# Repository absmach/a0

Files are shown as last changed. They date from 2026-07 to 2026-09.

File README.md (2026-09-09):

# 🔌 A0 Gateway

a0 is a modular **IoT gateway** built around the **ESP32-C6 (RISC-V)** platform, offering advanced wireless capabilities such as **Wi-Fi 6**, **Bluetooth 5**, and **802.15.4**. It supports multiple connectivity options including NB-IoT/LTE-M, WMBUS, and sub-GHz, enabling secure and scalable IoT deployments across smart buildings, industrial environments, and city infrastructure.

Optimized for low-power, battery-powered operation and modular expansion, A0 integrates secure communication, local storage, and multiple radio interfaces to serve as a versatile edge gateway in modern IoT ecosystems. While it includes support for Wireless and Wired M-Bus, its primary focus is on broad IoT connectivity and interoperability.

<p align="center">
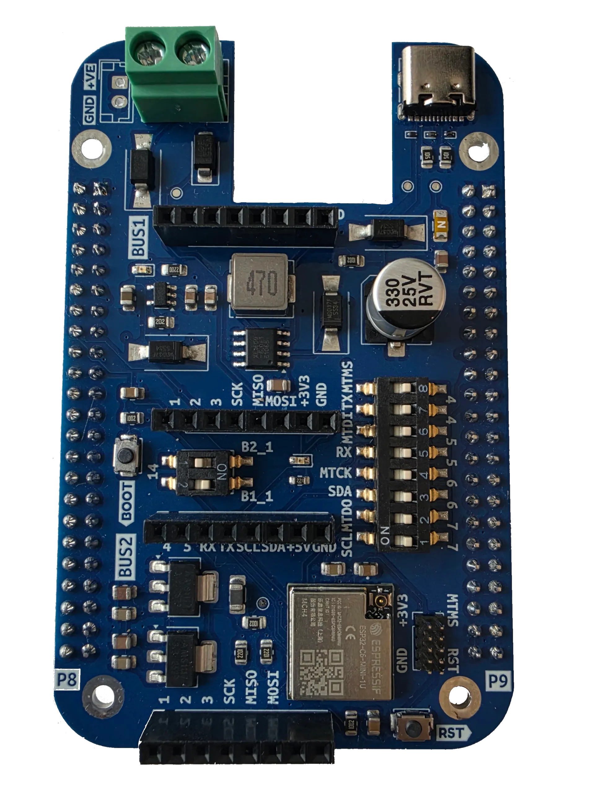
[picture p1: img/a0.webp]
A0 Board
  
</p>

## 🌟 Features

- ⚙️ **RISC-V Architecture**: Powered by ESP32-C6 with a RISC-V core for efficiency and flexibility.
- 📡 **Advanced Wireless Connectivity**: Supports Wi-Fi 6, Bluetooth 5, and 802.15.4 for robust IoT networking.
- 🌐 **Multiple Uplink Options**: Provides NB-IoT/LTE-M for reliable data transmission.
- 🔋 **Battery-Powered Operation**: Optimized for low-power deployments with long-lasting battery support.
- 🔐 **Advanced Security**: Includes RSA-3072 secure boot, AES-128/256-XTS flash encryption, digital signature, HMAC identity protection, and hardware cryptographic accelerators for performance. Built-in Trusted Execution Environment (TEE) ensures secure software separation.
- 🛠️ **Modular Design**: Optional carrier boards adds NB-IoT/LTE-M, WMBUS, and sub-GHz radio support.
- 🔗 **Flexible IoT Connectivity**: Integrates with [Magistrala](https://github.com/absmach/magistrala) using multiple IoT protocols, including MQTT, CoAP, HTTP, and WebSockets.
- 🧩 **Zephyr RTOS Support**: Compatible with Zephyr for real-time, reliable IoT applications.
- 🖥️ **WebAssembly Runtime**: Runs lightweight, portable edge logic with WAMR (WebAssembly Micro Runtime).
- 🌀 **Propeller Orchestrator Integration**: Works with [Propeller](https://github.com/absmach/propeller) for secure, policy-driven orchestration of IoT workloads across the edge-cloud continuum.
- 📈 **Future-Ready for IoT Ecosystems**: Designed for interoperability in smart buildings, industrial IoT, and city-scale deployments.

## 🛠️ How It Works

1. **Connect & Collect**  
   Gather data from IoT sensors and devices via Wireless/Wired M-Bus, Wi-Fi, BLE, or sub-GHz radio.

2. **Process at the Edge**  
   Use the **ESP32-C6** for real-time processing or deploy **WebAssembly (Wasm)** modules with **WAMR** for flexible edge logic execution.

3. **Ensure Security**  
   Protect data and code integrity with **secure boot**, **flash encryption**, and **TEE-based isolation**, leveraging ESP32-C6 hardware security features.

4. **Transmit to IoT Platform**  
   Send processed data using **NB-IoT/LTE-M**, supporting multiple protocols (**MQTT**, **CoAP**, **HTTP**, **WebSockets**) for seamless integration with [**Magistrala**](https://github.com/absmach/magistrala).

5. **Orchestrate & Scale**  
   Integrate with the [**Propeller Orchestrator**](https://github.com/absmach/propeller) for policy-driven deployment and orchestration of workloads across the edge-cloud continuum.

6. **Manage Remotely**  
   Perform **OTA updates**, monitor device health, and manage configurations through connected IoT management tools.

## 📖 Documentation

For setup instructions, pinouts, and integration guides, see the full documentation:  
🔗 [A0 Documentation](https://www.absmach.eu/docs/hardware/s1-gateway/)

## 💡 Use Cases

- 🏢 **Smart Buildings**: Connect heat and water meters via Wireless M-Bus for real-time monitoring.
- 🏭 **Industrial IoT**: Collect and transmit sensor data in secure and bandwidth-constrained environments.
- 🌍 **Smart Cities**: Enable large-scale metering infrastructure with NB-IoT and sub-GHz connectivity.
- 🔐 **Secure Data Acquisition**: Ensure encrypted communication from edge devices to the cloud.

## 🔧 Hardware Highlights

The system consists of a **base board (A0)** with plug-in **expansion modules**:

- **A0 Base Board** ([a0/](a0/README.md)):
  - MCU: **ESP32-C6** module (RISC-V architecture)
  - Connectivity: **Wi-Fi 6**, **Bluetooth 5**, **IEEE 802.15.4**
  - Security: **Secure Boot**, **Flash Encryption**, **TEE**, Hardware Crypto Accelerators
  - Power: **USB-C**, external power supply, or **battery** (with charging support)
  - Expansion: **2 module slots — BUS1 and BUS2** — for plug-in connectivity modules

- **Expansion Modules** (plug into BUS1/BUS2):
  - [**SIM7080G**](modules/sim7080g/README.md): NB-IoT / LTE-M cellular uplink + GNSS
  - [**WMBUS**](modules/wmbus/README.md): Wireless M-Bus metering radio
  - [**E07-400M10S**](modules/E07400M10S/README.md): Sub-GHz radio module (400 MHz, 10 dBm)

## 🤝 Contributing

Contributions are welcome! Please check the [CONTRIBUTING.md](#) for details on how to get started.

## 📜 License

A0 is licensed under the **Apache-2.0 License**. See the [LICENSE](LICENSE) file for more details.

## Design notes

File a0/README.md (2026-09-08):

# A0 Base Board

**A0** is the base board of the modular A0 IoT gateway, built around an **ESP32-C6 module** (RISC-V, Wi-Fi 6, Bluetooth 5, IEEE 802.15.4).

## About the ESP32-C6

The ESP32-C6 is Espressif's first Wi-Fi 6 SoC, integrating **2.4 GHz Wi-Fi 6 (802.11ax)**, **Bluetooth 5 (LE)** and **IEEE 802.15.4** (Thread/Zigbee) radio connectivity in a single low-power chip ([product page](https://www.espressif.com/en/products/socs/esp32-c6)).

| Spec | Details |
| --- | --- |
| **CPU** | High-performance 32-bit RISC-V core, up to **160 MHz**, plus a low-power (LP) 32-bit RISC-V core, up to **20 MHz** |
| **Memory** | 320 KB ROM, 512 KB SRAM, external flash |
| **Wireless** | 2.4 GHz Wi-Fi 6 (802.11ax, 20 MHz) with 802.11 b/g/n (20/40 MHz) backward compatibility; OFDMA up/downlink, downlink MU-MIMO, Target Wake Time (TWT); Bluetooth 5 LE with coded PHY long-range and 2 Mbps high-throughput PHY; IEEE 802.15.4 for Thread/Zigbee |
| **GPIO** | 30 (QFN40) or 22 (QFN32) programmable GPIOs |
| **Peripherals** | SPI, UART, I2C, I2S, RMT, TWAI, PWM, SDIO, Motor Control PWM, 12-bit ADC, temperature sensor |
| **Security** | RSA-3072 secure boot, AES-128/256-XTS flash encryption, digital signature and HMAC peripherals, hardware cryptographic accelerators, Trusted Execution Environment (TEE) for privilege/software separation |
| **Software** | Open-source ESP-IDF; ESP-Hosted / ESP-AT for co-processor use; ESP RainMaker; Zephyr support |

Wi-Fi 6 features (OFDMA, MU-MIMO, TWT) deliver low latency and long battery life even in congested RF environments, while combined Wi-Fi + BLE + 802.15.4 support makes it a natural fit for Matter end-point devices, Thread Border Routers, and Zigbee bridges.

## Overview

A0 provides everything needed to power and run the gateway, while pushing all radio/cellular connectivity onto removable expansion modules:

- **ESP32-C6 module on top** — main compute + Wi-Fi/BLE/802.15.4 connectivity, with hardware secure boot, flash encryption, and a TEE.
- **Power**:
  - USB-C power input
  - External power supply input
  - Battery support (with charging)
- **Expansion**: two module slots, **BUS1** and **BUS2**, where any of the following modules can be plugged in:
  - [SIM7080G](../modules/sim7080g/README.md) — NB-IoT/LTE-M cellular + GNSS
  - [WMBUS](../modules/wmbus/README.md) — Wireless M-Bus radio
  - [E07-400M10S](../modules/E07400M10S/README.md) — Sub-GHz radio (400 MHz, 10 dBm)

## Manufacturing

Gerber and assembly outputs are in [`jlcpcb/`](jlcpcb/) (`gerber/` and `production_files/`).

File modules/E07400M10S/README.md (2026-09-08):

# E07-400M10S Module

A plug-in expansion module for the [A0 base board](../../a0/README.md) based on the **Ebyte E07-400M10S** sub-GHz radio module.

## Overview

The E07-400M10S is a compact sub-GHz (400 MHz) RF transceiver module with 10 dBm output. Plug it into one of the A0 base board's expansion slots (**BUS1** or **BUS2**) to add low-power, long-range sub-GHz connectivity for private sensor networks and IEEE 802.15.4-style links.

## Key Features

- **Sub-GHz radio**: 400 MHz band, 10 dBm output power
- **Low power**: suited to battery-powered operation
- **Interface**: SPI / UART over the expansion bus
- **Power**: supplied from the expansion bus

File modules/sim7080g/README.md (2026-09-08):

# SIM7080G Module

A plug-in expansion module for the [A0 base board](../../a0/README.md) based on the **SIMCom SIM7080G**.

## Overview

The SIM7080G provides **NB-IoT / LTE-M (Cat-M)** cellular connectivity plus **GNSS** positioning. Plug it into one of the A0 base board's expansion slots (**BUS1** or **BUS2**) to add a reliable cellular uplink for NB-IoT and LTE-M deployments.

## Key Features

- **Cellular**: NB-IoT and LTE-M (Cat-M) uplink
- **GNSS**: GPS/GLONASS/BeiDou/Galileo positioning
- **Interface**: connects to the ESP32-C6 over UART via the expansion bus
- **Power**: supplied from the expansion bus

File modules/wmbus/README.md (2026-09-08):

# WMBUS Module

A plug-in expansion module for the [A0 base board](../../a0/README.md) implementing **Wireless M-Bus (EN 13757-4)**.

## Overview

The WMBUS module adds a Wireless M-Bus radio for reading utility meters (heat, water, gas, electricity). Plug it into one of the A0 base board's expansion slots (**BUS1** or **BUS2**) to enable smart metering deployments.

## Key Features

- **Wireless M-Bus (EN 13757-4)** communication
- Connects to the ESP32-C6 over the expansion bus
- Powered from the expansion bus

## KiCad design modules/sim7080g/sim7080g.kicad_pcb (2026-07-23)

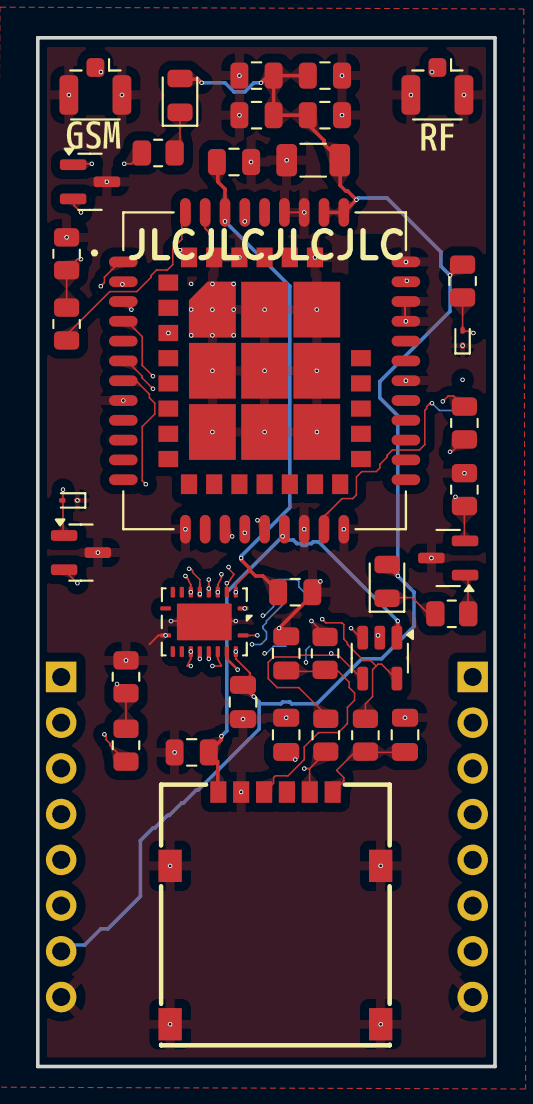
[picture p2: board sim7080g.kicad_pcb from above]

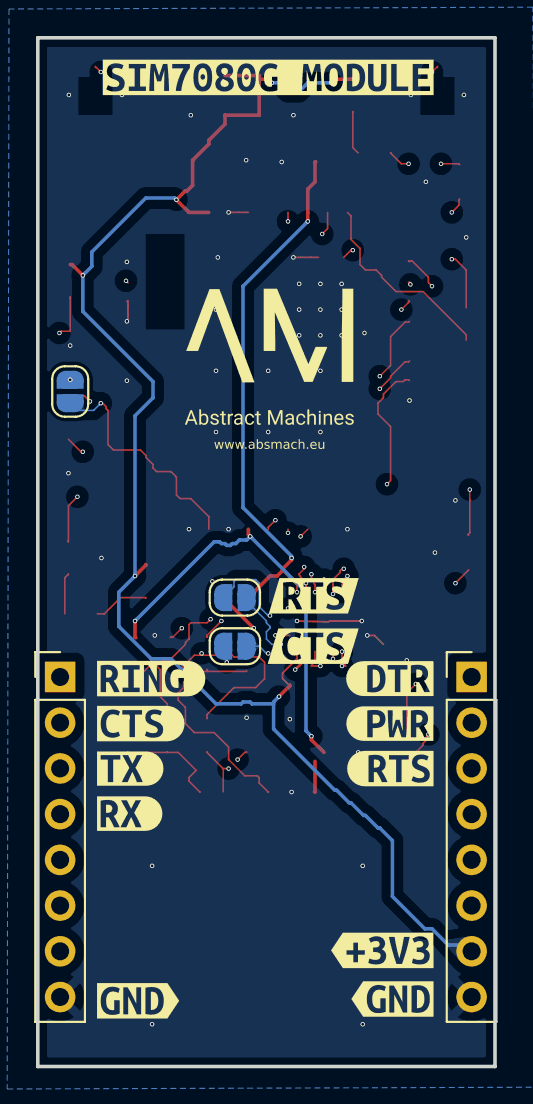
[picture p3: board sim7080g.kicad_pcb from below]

Board: 4 copper layers, 25.4 x 57.2 mm, 57 parts (18 on the bottom side), 39 nets.

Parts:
C1, C2, C5, C10, C11, C12, C13: 0.1uF; C_0805_2012Metric
C3: 10uF; C_0805_2012Metric
C6, C7, C8: 22pF; C_0805_2012Metric
C9: 100uF; C_1206_3216Metric
D1, D5: ESD9B5.0ST5G; D_SOD-923
D2: ESDA6V1SC5; SOT-23-5
D3, D4: LED; LED_0805_2012Metric
J1, J4: Conn_Coaxial; U.FL_Hirose_U.FL-R-SMT-1_Vertical
J2, J3: Conn_01x08; PinHeader_1x08_P2.54mm_Vertical
JP1, JP2, JP3: SolderJumper_2_Open; SolderJumper-2_P1.3mm_Open_RoundedPad1.0x1.5mm
Q1, Q2, Q3: NPN; SOT-23
R1: 10K; R_0805_2012Metric
R2, R8, R9: 4.7K; R_0805_2012Metric
R3, R4, R5: 22; R_0805_2012Metric
R6, R10, R11: 47K; R_0805_2012Metric
R7, R12: 100; R_0805_2012Metric
U1: TXB0108RGY; Texas_RGY_R-PVQFN-N20_EP2.05x3.05mm
U2: SIM7080G
U3: NANO SIM XG6P H1.35; SIM-SMD_NANO-SIM
kibuzzard-6A58AA2C: G***; kibuzzard-6A58AA2C
kibuzzard-6A58AA08: G***; kibuzzard-6A58AA08
kibuzzard-6A58AA80: G***; kibuzzard-6A58AA80
kibuzzard-6A58AA90: G***; kibuzzard-6A58AA90
kibuzzard-6A58AAA8: G***; kibuzzard-6A58AAA8
kibuzzard-6A58AAC0: G***; kibuzzard-6A58AAC0
kibuzzard-6A58AAD1: G***; kibuzzard-6A58AAD1
kibuzzard-6A58ABB3: G***; kibuzzard-6A58ABB3
kibuzzard-6A58ABC2: G***; kibuzzard-6A58ABC2
kibuzzard-6A58ABCC: G***; kibuzzard-6A58ABCC
kibuzzard-6A58ABD9: G***; kibuzzard-6A58ABD9
kibuzzard-6A58ABE5: G***; kibuzzard-6A58ABE5
kibuzzard-6A58AD62: G***; kibuzzard-6A58AD62
kibuzzard-6A58AD87: G***; kibuzzard-6A58AD87
kibuzzard-6A58ADF5: G***; kibuzzard-6A58ADF5

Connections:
+1V8: C1.2, C3.2, U1.2 (V_{CCA}), U2.40 (VDD_EXT)
+3V3: C2.2, C9.1, C10.1, C11.1, C12.1, C13.1, D3.2 (A), D4.2 (A), J2.7, R1.1, U1.19 (V_{CCB}), U2.34 (VBAT), U2.35 (VBAT__1)
GND: C1.1, C2.1, C3.1, C5.1, C6.1, C7.1, C8.1, C9.2, C10.2, C11.2, C12.2, C13.2, D1.1 (A1), D2.2 (A), D5.1 (A1), J1.2 (Ext), J2.8, J3.8, J4.2 (Ext), Q1.3 (E), Q2.3 (E), Q3.3 (E), R6.2, R10.2, R11.2, U1.11 (GND), U1.21 (GND), U2.8 (GND), U2.13 (GND__1), U2.19 (GND__2), U2.21 (GND__3), U2.27 (GND__4), U2.30 (GND__5), U2.31 (GND__6), U2.33 (GND__7), U2.36 (GND__8), U2.37 (GND__9), U2.45 (GND__10), U2.63 (GND__11), U2.66 (GND__12), U2.67 (GND__13), U2.69 (GND__14), U2.70 (GND__15), U2.71 (GND__16), U2.72 (GND__17), U2.73 (GND__18), U2.74 (GND__19), U2.75 (GND__20), U2.76 (GND__21), U2.77 (GND__22), U3.5 (GND), U3.8 (GND), U3.9 (GND), U3.10 (GND), U3.11 (GND)
GNSS_ANT: J1.1 (In), U2.68 (GNSS_ANT)
NETLIGHT: R9.1, U2.41 (NETLIGHT)
unnamed: D1.2 (A2), JP1.1 (A), R1.2
unnamed: D3.1 (K), R7.2
unnamed: D4.1 (K), R12.2
unnamed: JP1.2 (B), U2.20 (USB_BOOT)
unnamed: JP2.1 (A), U1.17 (B3)
unnamed: JP3.1 (A), U1.16 (B4)
unnamed: Q1.2 (B), R2.2, R6.1
unnamed: Q1.1 (C), R7.1
unnamed: Q2.2 (B), R8.2, R11.1
unnamed: Q3.2 (B), R9.2, R10.1
unnamed: Q3.1 (C), R12.1
unnamed: C7.2, R4.2, U3.3 (CLK)
unnamed: C8.2, R5.2, U3.7 (I/O)
unnamed: C6.2, R3.2, U3.2 (RST)
PWRKEY: D5.2 (A2), Q2.1 (C), U2.39 (PWRKEY)
RF_ANT: J4.1 (In), U2.32 (RF_ANT)
SIM7080G_CTS: J3.2, JP3.2 (B)
SIM7080G_DTR: J2.1, U1.15 (B5)
SIM7080G_PWR: J2.2, R8.1
SIM7080G_RING: J3.1, U1.14 (B6)
SIM7080G_RTS: J2.3, JP2.2 (B)
SIM7080G_RX: J3.4, U1.18 (B2)
SIM7080G_TX: J3.3, U1.20 (B1)
SIM_CLK: D2.4 (K), R4.1, U2.16 (SIM_CLK)
SIM_CTS: U1.5 (A4), U2.4 (UART1_CTS)
SIM_DATA: D2.5 (K), R5.1, U2.15 (SIM_DATA)
SIM_DTR: U1.6 (A5), U2.6 (UART1_DTR)
SIM_RI: U1.7 (A6), U2.7 (UART1_RI)
SIM_RST: D2.3 (K), R3.1, U2.17 (SIM_RST)
SIM_RTS: U1.4 (A3), U2.3 (UART1_RTS)
SIM_RX: U1.3 (A2), U2.2 (UART1_RXD)
SIM_TX: U1.1 (A1), U2.1 (UART1_TXD)
SIM_VDD: C5.2, D2.1 (K), U2.18 (SIM_VDD), U3.1 (VCC)
STATUS: R2.1, U2.42 (STATUS)

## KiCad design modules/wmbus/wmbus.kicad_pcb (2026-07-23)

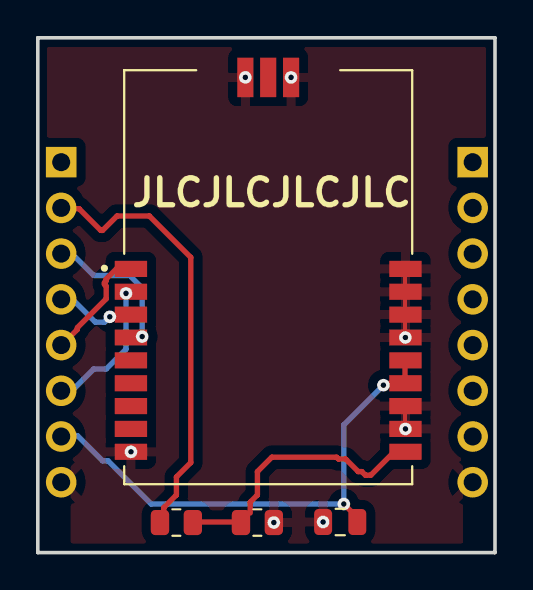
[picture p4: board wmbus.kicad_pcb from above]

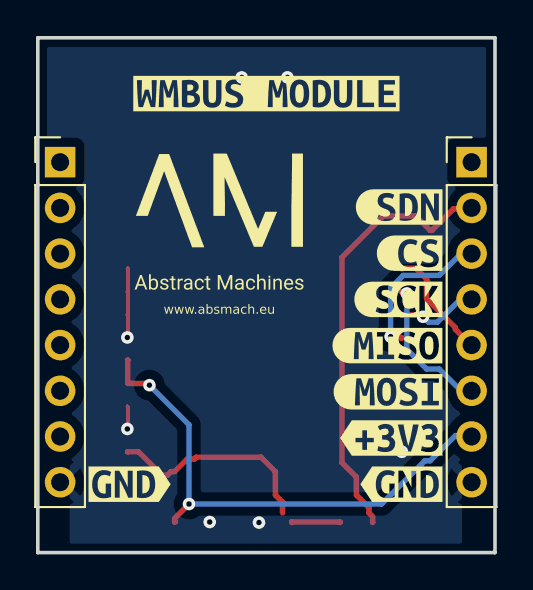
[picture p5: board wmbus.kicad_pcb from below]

Board: 2 copper layers, 25.4 x 28.6 mm, 15 parts (11 on the bottom side), 8 nets.

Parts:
C1: 0.1uF; C_0805_2012Metric
J1, J2: Conn_01x08; PinHeader_1x08_P2.54mm_Vertical
R1: 100; R_0805_2012Metric
R2: 10K; R_0805_2012Metric
U2: RC-S2LP-868
kibuzzard-6A563B7D: G***; kibuzzard-6A563B7D
kibuzzard-6A563B31: G***; kibuzzard-6A563B31
kibuzzard-6A563B41: G***; kibuzzard-6A563B41
kibuzzard-6A563B50: G***; kibuzzard-6A563B50
kibuzzard-6A563B65: G***; kibuzzard-6A563B65
kibuzzard-6A563B71: G***; kibuzzard-6A563B71
kibuzzard-6A563B88: G***; kibuzzard-6A563B88
kibuzzard-6A563B96: G***; kibuzzard-6A563B96
kibuzzard-6A563BEF: G***; kibuzzard-6A563BEF

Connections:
+3V3: C1.1, J1.7, U2.13 (VCC), U2.14 (VCC)
CS: J1.3, U2.4 (CSN)
GND: C1.2, J1.8, J2.8, R2.2, U2.9 (GND), U2.11 (GND), U2.12 (GND), U2.15 (GND), U2.16 (GND), U2.17 (GND), U2.18 (GND), U2.19 (GND), U2.21 (GND)
MISO: J1.5, U2.1 (SDO)
MOSI: J1.6, U2.2 (SDI)
unnamed: R1.2, R2.1, U2.10 (SDN)
SCK: J1.4, U2.3 (SCLK)
SDN: J1.2, R1.1

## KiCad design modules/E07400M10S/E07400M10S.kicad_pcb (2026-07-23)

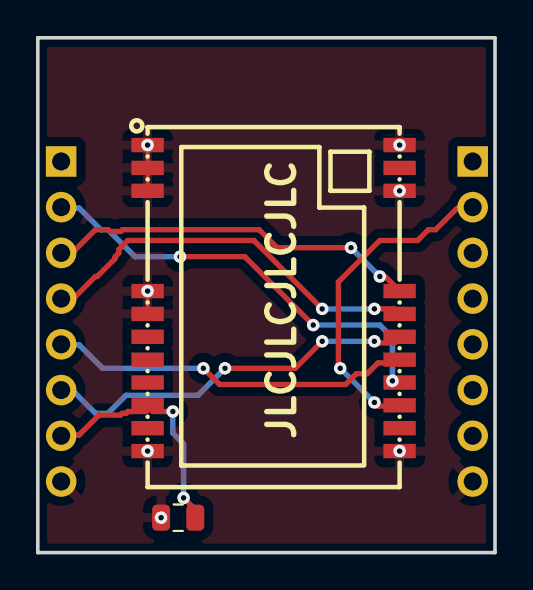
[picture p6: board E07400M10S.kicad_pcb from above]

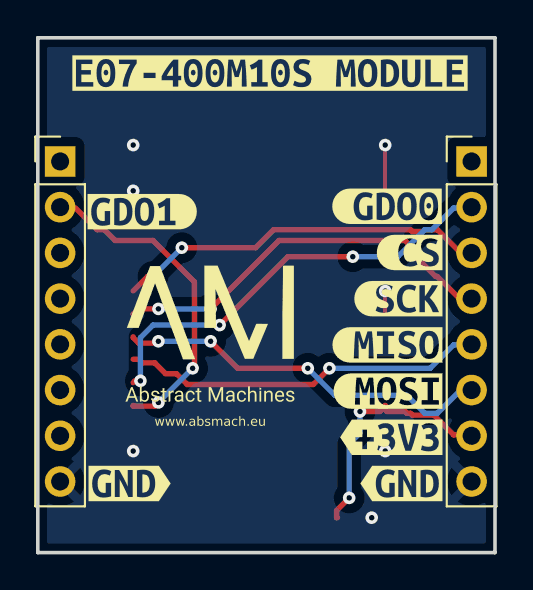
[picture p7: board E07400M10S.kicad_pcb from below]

Board: 2 copper layers, 25.4 x 28.6 mm, 14 parts (12 on the bottom side), 8 nets.

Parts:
C1: 0.1uF; C_0805_2012Metric
J1, J2: Conn_01x08; PinHeader_1x08_P2.54mm_Vertical
U1: E07-400M10S; C2965513
kibuzzard-6A5A4D23: G***; kibuzzard-6A5A4D23
kibuzzard-6A5A4D79: G***; kibuzzard-6A5A4D79
kibuzzard-6A5A4D90: G***; kibuzzard-6A5A4D90
kibuzzard-6A563B7D: G***; kibuzzard-6A563B7D
kibuzzard-6A563B41: G***; kibuzzard-6A563B41
kibuzzard-6A563B50: G***; kibuzzard-6A563B50
kibuzzard-6A563B65: G***; kibuzzard-6A563B65
kibuzzard-6A563B71: G***; kibuzzard-6A563B71
kibuzzard-6A563B88: G***; kibuzzard-6A563B88
kibuzzard-6A563B96: G***; kibuzzard-6A563B96

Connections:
+3V3: C1.1, J1.7, U1.9 (VCC)
CS: J1.3, U1.19 (CSN)
GDO0: J1.2, U1.15 (GD00)
GDO1: J2.2, U1.14 (GD02)
GND: C1.2, J1.8, J2.8, U1.1 (GND), U1.2 (GND), U1.3 (GND), U1.4 (GND), U1.5 (GND), U1.11 (GND), U1.12 (GND), U1.20 (GND), U1.22 (GND)
MISO: J1.5, U1.16 (MISO/GD01)
MOSI: J1.6, U1.17 (MOSI)
SCK: J1.4, U1.18 (SCK)

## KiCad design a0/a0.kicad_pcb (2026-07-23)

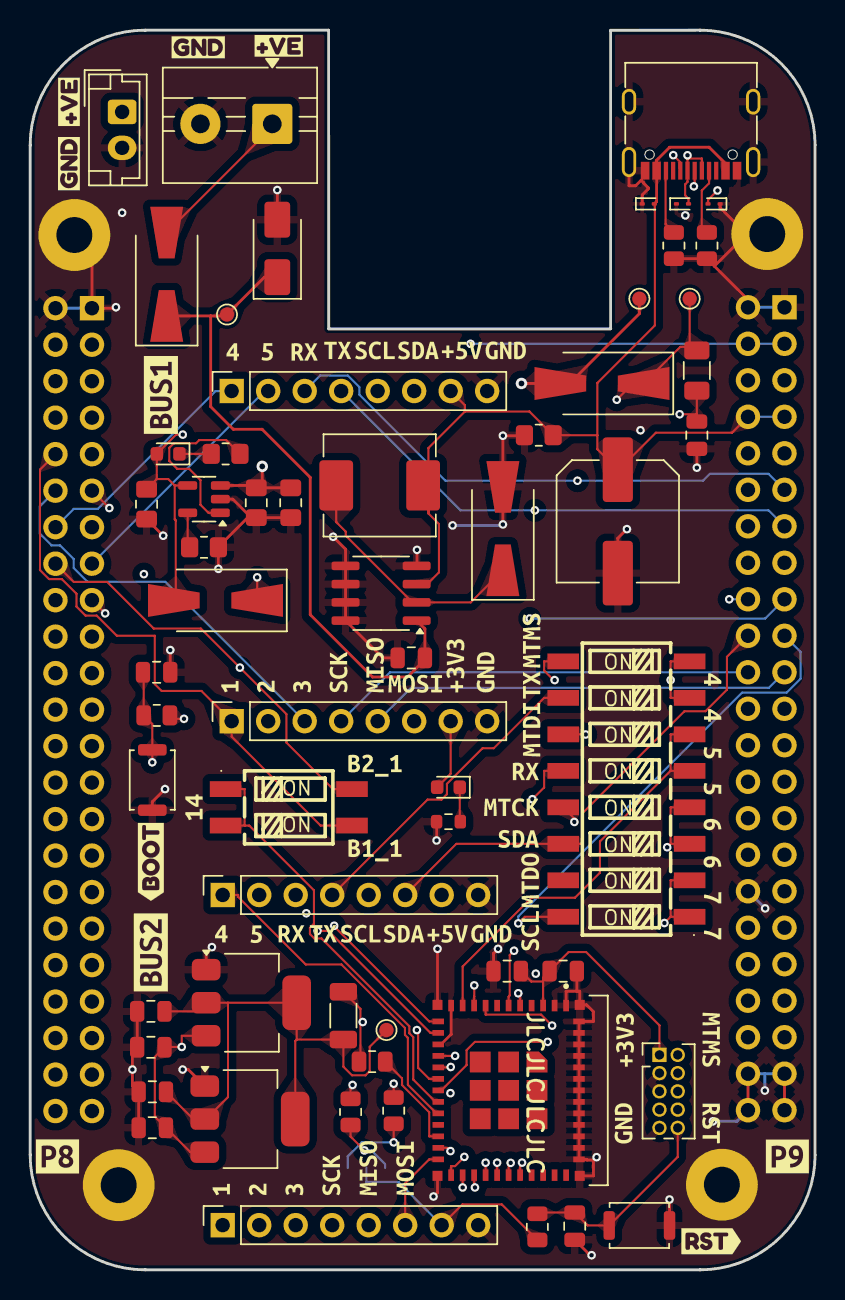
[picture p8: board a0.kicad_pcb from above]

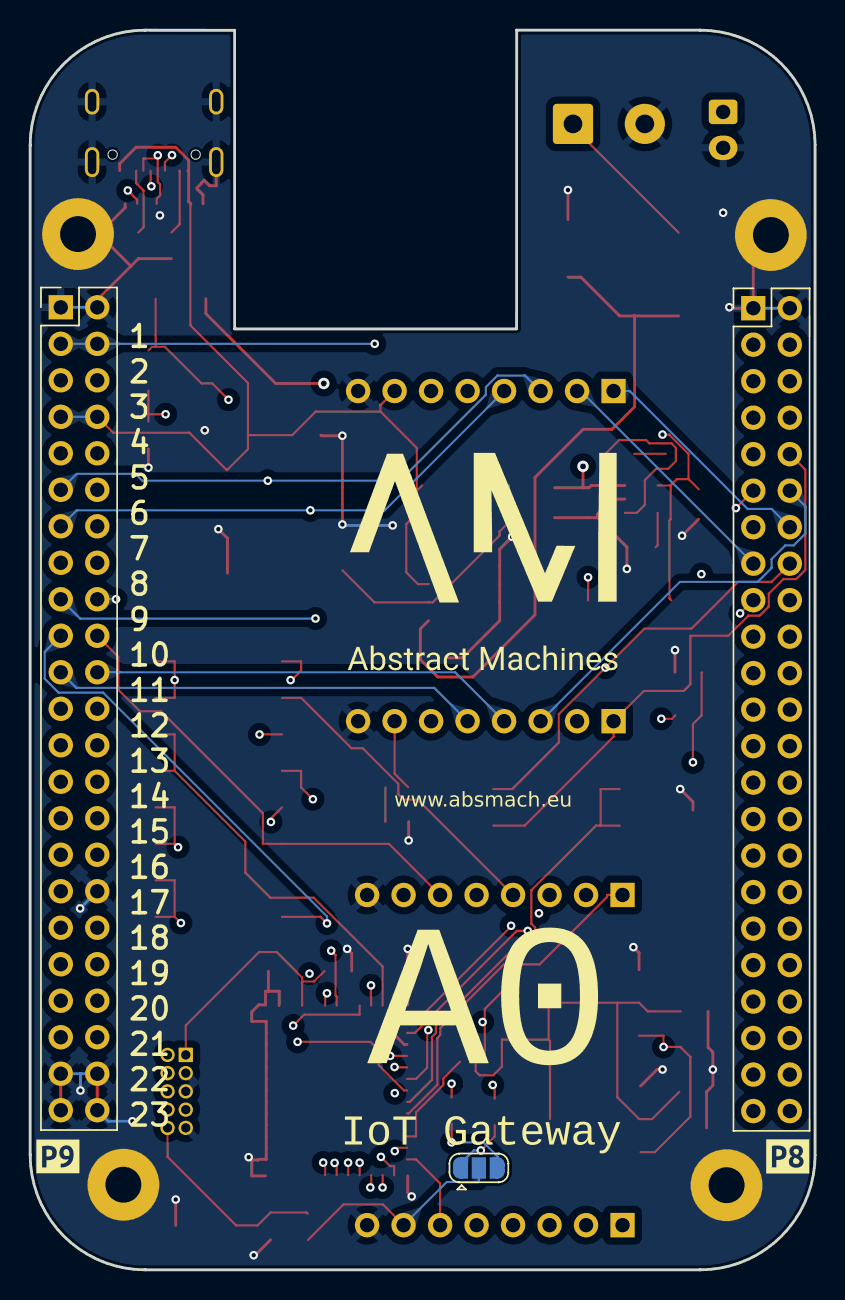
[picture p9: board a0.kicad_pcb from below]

Board: 4 copper layers, 54.6 x 86.3 mm, 131 parts (5 on the bottom side), 50 nets.

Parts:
C1, C2: 1uF; C_0805_2012Metric
C3: 22uF; C_0805_2012Metric
C4, C10, C11: 0.1uF; C_0805_2012Metric
C5, C6, C7: 4.7uF; C_0805_2012Metric_Pad1.18x1.45mm_HandSolder
C8, C9, C12, C13: 10uF; C_0805_2012Metric
C14: 330uF; C_Elec_8x10.2
D1, D7, D8, D9: 40V 3A 550mV@3A Schottky; D_SMA-SMB_Universal_Handsoldering
D2, D3, D4: ESD9B5.0ST5G; D_SOD-923
D5: BZV55C27; D_SMA
D6, D10: LED; LED_0603_1608Metric
F1: Fuse; Fuse_1206_3216Metric
FB1: FerriteBead; L_1206_3216Metric_Pad1.22x1.90mm_HandSolder
H1, H2, H3, H4: MountingHole_Pad; MountingHole_2.5mm_Pad
J1, J2, J3, J4: Conn_01x08; PinSocket_1x08_P2.54mm_Vertical
J5: Beagle P8; PinHeader_2x23_P2.54mm_Vertical
J6: Beagle P9; PinHeader_2x23_P2.54mm_Vertical
J7: ESP32 USB; USB_C_Receptacle_G-Switch_GT-USB-7010ASV
J8: Screw_Terminal_01x02; TerminalBlock_MaiXu_MX126-5.0-02P_1x02_P5.00mm
J9: BAT_JST_01x02; JST_EH_B2B-EH-A_1x02_P2.50mm_Vertical
J10: Conn_ARM_JTAG_SWD_10; PinHeader_2x05_P1.27mm_Vertical
JP1: SolderJumper_3_Open; SolderJumper-3_P1.3mm_Open_RoundedPad1.0x1.5mm
L1: 47uH/2A; L_Chilisin_BMRB00060624
R1, R4, R5: 10K; R_0805_2012Metric
R2, R3: 2.2K; R_0805_2012Metric
R6, R7: 5K1; R_0805_2012Metric
R8: 2k; R_0805_2012Metric_Pad1.20x1.40mm_HandSolder
R9: 220; R_0805_2012Metric_Pad1.20x1.40mm_HandSolder
R10: 10k; R_0805_2012Metric_Pad1.20x1.40mm_HandSolder
R11: 220; R_0603_1608Metric
SW1, SW2: SW_Push; SW_Push_SPST_NO_Alps_SKRK
SW5: SMXS-08K-TP; C5439767
TP1, TP2, TP3, TP4: TestPoint; TestPoint_Pad_D1.0mm
U1: SMXS-02K-TP; C5439761
U4: ESP32-C6-MINI-1/U; XCVR_ESP32-C3-MINI-1U-N4
U5: MCP73831-2-OT; SOT-23-5
U6: XL1509-5.0; SOIC-8_3.9x4.9mm_P1.27mm
U7, U8: AMS1117-3.3; SOT-223-3_TabPin2
kibuzzard-6A55FB86, kibuzzard-6A55FB8650: G***; kibuzzard-6A55FB86
kibuzzard-6A55FB93, kibuzzard-6A55FB9349: G***; kibuzzard-6A55FB93
kibuzzard-6A55FC6E7: G***; kibuzzard-6A55FC6E
kibuzzard-6A55FC8415: G***; kibuzzard-6A55FC84
kibuzzard-6A55FD1132: G***; kibuzzard-6A55FD11
kibuzzard-6A55FD3129: G***; kibuzzard-6A55FD31
kibuzzard-6A55FD6527: G***; kibuzzard-6A55FD65
kibuzzard-6A55FD7025: G***; kibuzzard-6A55FD70
kibuzzard-6A55FE0F26: G***; kibuzzard-6A55FE0F
kibuzzard-6A55FE7B11: G***; kibuzzard-6A55FE7B
kibuzzard-6A55FE1730: G***; kibuzzard-6A55FE17
kibuzzard-6A55FE2828: G***; kibuzzard-6A55FE28
kibuzzard-6A55FE3524: G***; kibuzzard-6A55FE35
kibuzzard-6A55FE7212: G***; kibuzzard-6A55FE72
kibuzzard-6A55FE9913: G***; kibuzzard-6A55FE99
kibuzzard-6A55FEAA10: G***; kibuzzard-6A55FEAA
kibuzzard-6A55FFC232: G***; kibuzzard-6A55FFC2
kibuzzard-6A55FFC933: G***; kibuzzard-6A55FFC9
kibuzzard-6A55FFCE34: G***; kibuzzard-6A55FFCE
kibuzzard-6A55FFD235: G***; kibuzzard-6A55FFD2
kibuzzard-6A55FFD736: G***; kibuzzard-6A55FFD7
kibuzzard-6A55FFDB37: G***; kibuzzard-6A55FFDB
kibuzzard-6A55FFDF38: G***; kibuzzard-6A55FFDF
kibuzzard-6A55FFE439: G***; kibuzzard-6A55FFE4
kibuzzard-6A5604D22: G***; kibuzzard-6A5604D2
kibuzzard-6A5604E99: G***; kibuzzard-6A5604E9
kibuzzard-6A56002C: G***; kibuzzard-6A56002C
kibuzzard-6A56005A: G***; kibuzzard-6A56005A
kibuzzard-6A56010B2, kibuzzard-6A56010B41: G***; kibuzzard-6A56010B
kibuzzard-6A56011A4, kibuzzard-6A56011A43: G***; kibuzzard-6A56011A
kibuzzard-6A56012F5, kibuzzard-6A56012F44: G***; kibuzzard-6A56012F
kibuzzard-6A56013C46: G***; kibuzzard-6A56013C
kibuzzard-6A56014C, kibuzzard-6A56014C19: G***; kibuzzard-6A56014C
kibuzzard-6A56016F, kibuzzard-6A56016F17: G***; kibuzzard-6A56016F
kibuzzard-6A56043E14: G***; kibuzzard-6A56043E
kibuzzard-6A56059C1: G***; kibuzzard-6A56059C
kibuzzard-6A560036: G***; kibuzzard-6A560036
kibuzzard-6A560120, kibuzzard-6A56012020: G***; kibuzzard-6A560120
kibuzzard-6A560129, kibuzzard-6A56012921: G***; kibuzzard-6A560129
kibuzzard-6A560142, kibuzzard-6A56014223, kibuzzard-6A56014247: G***; kibuzzard-6A560142
kibuzzard-6A560146, kibuzzard-6A56014618: G***; kibuzzard-6A560146
kibuzzard-6A560169, kibuzzard-6A56016916: G***; kibuzzard-6A560169
kibuzzard-6A560175, kibuzzard-6A56017522: G***; kibuzzard-6A560175
kibuzzard-6A5601031, kibuzzard-6A56010340: G***; kibuzzard-6A560103
kibuzzard-6A5601133, kibuzzard-6A56011342: G***; kibuzzard-6A560113
kibuzzard-6A5601356, kibuzzard-6A56013545: G***; kibuzzard-6A560135
kibuzzard-6A5605438: G***; kibuzzard-6A560543
kibuzzard-6A56041948: G***; kibuzzard-6A560419

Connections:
+3V3: C3.1, C4.1, D10.2 (A), FB1.2, J1.7, J4.7, J6.3, J6.4, J10.1 (VTref), JP1.2 (C), R1.1, R4.1, R5.1, U4.3 (3V3)
FB_5V: C5.1, C14.1, D2.2 (A2), D6.2 (A), D8.2 (A), J2.7, J3.7, J6.7, J6.8, J7.A4 (VBUS), J7.A9 (VBUS), J7.B4 (VBUS), J7.B9 (VBUS), L1.2, R10.2, U5.4 (V_{DD}), U6.3 (FB)
GND: C1.2, C2.2, C3.2, C4.2, C5.2, C6.2, C7.2, C8.2, C9.2, C10.2, C11.2, C12.2, C13.2, C14.2, D2.1 (A1), D3.1 (A1), D4.1 (A1), D5.2 (A), D9.2 (A), H1.1, H2.1, H3.1, H4.1, J1.8, J2.8, J3.8, J4.8, J5.1, J5.2, J6.1, J6.2, J6.34, J6.43, J6.44, J6.45, J6.46, J7.A1 (GND), J7.A12 (GND), J7.B1 (GND), J7.B12 (GND), J7.S1 (SHIELD), J8.2, J9.2, J10.3 (GND), J10.5 (GND), J10.9 (GNDDetect), R6.2, R7.2, R8.1, R10.1, R11.2, SW1.1, SW2.1, U4.1 (GND), U4.2 (GND), U4.11 (GND), U4.14 (GND), U4.36 (GND), U4.37 (GND), U4.38 (GND), U4.39 (GND), U4.40 (GND), U4.41 (GND), U4.42 (GND), U4.43 (GND), U4.44 (GND), U4.45 (GND), U4.46 (GND), U4.47 (GND), U4.48 (GND), U4.50 (GND), U4.51 (GND), U4.52 (GND), U4.53 (GND), U5.2 (V_{SS}), U6.4 (~EN), U6.5 (GND), U6.6 (GND), U6.7 (GND), U6.8 (GND), U7.1 (GND), U8.1 (GND)
GPIO4: SW5.7, SW5.8, U4.9 (MTMS/GPIO4/ADC1_CH4)
GPIO5: SW5.5, SW5.6, U4.10 (MTDI/GPIO5/ADC1_CH5)
GPIO6: SW5.3, SW5.4, U4.15 (MTCK/GPIO6/ADC1_CH6)
GPIO7: SW5.1, SW5.2, U4.16 (MTDO/GPIO7)
GPIO8: R5.2, U4.22 (GPIO8)
GPIO9: C2.1, R4.2, SW2.2, U4.23 (GPIO9)
GPIO14: U1.1, U1.2, U4.19 (GPIO14)
MCU_RST: C1.1, J10.10 (~RESET), R1.2, SW1.2, U4.8 (EN/CHIP_PU)
MISO: J1.5, J4.5, J6.21, U4.25 (GPIO19)
MOSI: J1.6, J4.6, J6.18, U4.24 (GPIO18)
MTCK: J10.4 (SWCLK/TCK), SW5.13
MTDI: J10.8 (NC/TDI), SW5.11
MTMS: J10.2 (SWDIO/TMS), SW5.9
MiBUS1_1: J1.1, J5.10, U1.3
MiBUS1_2: J1.2, J5.11, U4.13 (GPIO1/ADC1_CH1/XTAL_32K_N)
MiBUS1_3: J1.3, J5.12, U4.5 (GPIO2/ADC1_CH2)
MiBUS1_4: J3.1, J5.14, U4.6 (GPIO3/ADC1_CH3)
MiBUS1_5: J3.2, J5.15, U4.12 (GPIO0/ADC1_CH0/XTAL_32K_P)
MiBUS1_RX: J3.3, J6.11, U4.31 (U0TXD/GPIO16)
MiBUS1_TX: J3.4, J6.13, U4.30 (U0RXD/GPIO17)
MiBUS2_1: J4.1, J5.16, U1.4
MiBUS2_2: J4.2, J5.17, U4.28 (GPIO22)
MiBUS2_3: J4.3, J6.17, U4.27 (GPIO21)
MiBUS2_4: J2.1, U4.20 (GPIO15)
MiBUS2_5: J2.2, U4.29 (GPIO23)
MiBUS2_RX: J2.3, SW5.12
MiBUS2_TX: J2.4, SW5.10
unnamed: D1.2 (A), J8.1
unnamed: D6.1 (K), R9.1
unnamed: D7.1 (K), D8.1 (K), F1.1, TP3.1
unnamed: D9.1 (K), L1.1, U6.2 (OUT)
unnamed: D10.1 (K), R11.1
unnamed: J7.A5 (CC1), R7.1
unnamed: J7.B5 (CC2), R6.1
unnamed: JP1.1 (A), R3.1
unnamed: JP1.3 (B), R2.2
unnamed: R8.2, U5.5 (PROG)
unnamed: R9.2, U5.1 (STAT)
unnamed: C9.1, C10.1, C11.1, F1.2, U7.3 (VI), U8.3 (VI)
unnamed: C12.1, C13.1, FB1.1, TP4.1, U7.2 (VO), U8.2 (VO)
SCK: J1.4, J4.4, J6.22, U4.26 (GPIO20)
SCL: J2.5, J3.5, J6.19, R3.2, SW5.16
SDA: J2.6, J3.6, J6.20, R2.1, SW5.14
USB_D+: D4.2 (A2), J7.A6 (D+), J7.B6 (D+), U4.18 (GPIO13/USB_D+)
USB_D-: D3.2 (A2), J7.A7 (D-), J7.B7 (D-), U4.17 (GPIO12/USB_D-)
VBAT: C6.1, C7.1, D7.2 (A), J9.1, TP2.1, U5.3 (V_{BAT})
VIN: C8.1, D1.1 (K), D5.1 (K), TP1.1, U6.1 (VIN)

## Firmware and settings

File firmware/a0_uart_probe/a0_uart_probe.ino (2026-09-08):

// A0 / SIM7080G UART probe.
//
// Resolves the contradiction between "the edge counter saw thousands of
// transitions" and "UART1 received zero bytes". Two independent tools:
//
//   cap   detach UART1, timestamp raw edges on GPIO16, and histogram the
//         intervals. The most common SHORT interval is one bit period, so
//         this measures the modem's actual baud rate without depending on
//         UART framing at all.  baud = 1e6 / bit_period_us
//
//   d/u/f switch GPIO16's internal pull (45k typ) to tell a genuinely driven
//         line from a floating one. Against the TXB0108's ~4k output a real
//         drive holds at ~3.0 V; a floating line follows the pull.
//
// PWRKEY is manual. GPIO16's idle level doubles as a power-state indicator,
// because U1's VCCA comes from the modem's own VDD_EXT.
//
// Build with USB CDC On Boot = Enabled.

#define MODEM_RX_PIN 16
#define MODEM_TX_PIN 17

HardwareSerial Modem(1);

static const uint16_t kCapN = 2048;
static volatile uint32_t g_cap[kCapN];
static volatile uint16_t g_capIdx  = 0;
static volatile bool     g_capArm  = false;

static uint32_t g_rxBytes = 0;
static uint32_t g_baud    = 115200;
static bool     g_uartOn  = true;
static const char *g_pull = "floating";

static void IRAM_ATTR capISR() {
  if (g_capArm && g_capIdx < kCapN) g_cap[g_capIdx++] = micros();
}

static void uartOff() {
  if (g_uartOn) { Modem.end(); delay(20); g_uartOn = false; }
  pinMode(MODEM_RX_PIN, INPUT);
}

static void uartOn(uint32_t baud) {
  detachInterrupt(digitalPinToInterrupt(MODEM_RX_PIN));
  if (g_uartOn) { Modem.end(); delay(20); }
  // Nothing may touch this pin's mode after begin() - that is what detaches
  // the peripheral input routing and gives you edges but zero bytes.
  Modem.begin(baud, SERIAL_8N1, MODEM_RX_PIN, MODEM_TX_PIN);
  g_baud = baud; g_uartOn = true;
  Serial.printf("\nUART1 attached at %lu bps\n", (unsigned long)baud);
}

static void dumpByte(uint8_t b) {
  g_rxBytes++;
  if (b == '\r' || b == '\n' || (b >= 0x20 && b < 0x7F)) Serial.write(b);
  else Serial.printf("[%02X]", b);
}

static void capture(uint32_t windowMs) {
  uartOff();
  attachInterrupt(digitalPinToInterrupt(MODEM_RX_PIN), capISR, CHANGE);

  Serial.printf("\nCapturing raw edges for %lu ms - pulse PWRKEY NOW if the "
                "modem is off.\n", (unsigned long)windowMs);
  g_capIdx = 0;
  g_capArm = true;
  uint32_t t0 = millis();
  while (millis() - t0 < windowMs && g_capIdx < kCapN) delay(1);
  g_capArm = false;

  uint16_t n = g_capIdx;
  Serial.printf("edges captured: %u%s\n", n, n >= kCapN ? " (buffer full)" : "");
  if (n < 8) {
    Serial.println("Too few edges. The line is not transitioning.");
    attachInterrupt(digitalPinToInterrupt(MODEM_RX_PIN), capISR, CHANGE);
    return;
  }

  // Histogram intervals 1..200 us in 1 us bins. A UART's most common short
  // interval is exactly one bit period.
  static uint16_t hist[201];
  memset(hist, 0, sizeof(hist));
  uint32_t over = 0;
  for (uint16_t i = 1; i < n; i++) {
    uint32_t d = g_cap[i] - g_cap[i - 1];
    if (d >= 1 && d <= 200) hist[d]++;
    else over++;
  }

  Serial.println("\ntop intervals (us : count):");
  for (uint8_t k = 0; k < 6; k++) {
    uint16_t best = 0, bestIdx = 0;
    for (uint16_t i = 1; i <= 200; i++)
      if (hist[i] > best) { best = hist[i]; bestIdx = i; }
    if (!best) break;
    Serial.printf("  %3u us : %u\n", bestIdx, best);
    hist[bestIdx] = 0;
  }
  Serial.printf("  >200us or 0: %lu\n", (unsigned long)over);

  Serial.println("\nIf a clear shortest peak exists, baud = 1000000/that:");
  Serial.println("   8-9us=115200  17us=57600  26us=38400  52us=19200  104us=9600");
  Serial.println("A flat smear with many 1-3us intervals means the line is");
  Serial.println("floating and self-oscillating, not carrying data.");
}

static void pullTest(const char *name, uint8_t mode) {
  uartOff();
  pinMode(MODEM_RX_PIN, mode);
  g_pull = name;
  delay(20);
  Serial.printf("\nGPIO16 %s -> %s\n", name,
                digitalRead(MODEM_RX_PIN) ? "HIGH" : "LOW");
  if (mode == INPUT_PULLDOWN)
    Serial.println("  HIGH = U1 really is driving.  LOW = floating, U1 is not.");
  if (mode == INPUT_PULLUP)
    Serial.println("  LOW = something really pulls it down.  HIGH = floating.");
  attachInterrupt(digitalPinToInterrupt(MODEM_RX_PIN), capISR, CHANGE);
}

static bool sendAT(const String &cmd, uint32_t timeoutMs) {
  if (!g_uartOn) { Serial.println("\nUART detached - type 'uart' first."); return false; }
  while (Modem.available()) Modem.read();
  Modem.print(cmd); Modem.print("\r\n");
  String reply; uint32_t t0 = millis();
  while (millis() - t0 < timeoutMs) {
    while (Modem.available()) { char c = Modem.read(); reply += c; dumpByte(c); }
    if (reply.indexOf("OK") >= 0 || reply.indexOf("ERROR") >= 0) break;
  }
  return reply.indexOf("OK") >= 0;
}

static void help() {
  Serial.println();
  Serial.println("  cap      - detach UART, capture raw edges, histogram baud");
  Serial.println("  d / u / f- GPIO16 pull-down / pull-up / float test");
  Serial.println("  uart     - re-attach UART1 at the current baud");
  Serial.println("  b<rate>  - set baud and attach, e.g. b9600");
  Serial.println("  at       - probe AT 10x");
  Serial.println("  scan     - sweep baud rates");
  Serial.println("  ?        - this list");
  Serial.println();
}

static void baudScan() {
  static const uint32_t r[] = {115200, 9600, 19200, 38400, 57600, 230400, 460800};
  for (uint8_t i = 0; i < sizeof(r) / sizeof(r[0]); i++) {
    uartOn(r[i]);
    delay(150);
    for (uint8_t k = 0; k < 4; k++) {
      Serial.printf("  %lu try %u: ", (unsigned long)r[i], k + 1);
      if (sendAT("AT", 800)) { Serial.printf("\n*** OK at %lu ***\n", (unsigned long)r[i]); return; }
      Serial.println();
    }
  }
  Serial.println("no response at any rate");
}

void setup() {
  Serial.begin(115200);
  Modem.begin(g_baud, SERIAL_8N1, MODEM_RX_PIN, MODEM_TX_PIN);
  delay(1500);
  Serial.println();
  Serial.println("========================================");
  Serial.println(" A0 / SIM7080G UART probe");
  Serial.println("========================================");
  help();
}

void loop() {
  static String line;
  static uint32_t last = 0;
  static bool wasOn = false;

  if (g_uartOn) while (Modem.available()) dumpByte(Modem.read());

  if (millis() - last >= 2000) {
    last = millis();
    bool on = g_uartOn ? digitalRead(MODEM_RX_PIN) : digitalRead(MODEM_RX_PIN);
    if (on != wasOn) { Serial.printf("\n*** modem went %s ***\n", on ? "ON" : "OFF"); wasOn = on; }
    Serial.printf("[MODEM %s | uart %s %lu | pull %s | rx=%lu]\n",
                  on ? "ON " : "OFF", g_uartOn ? "on " : "off",
                  (unsigned long)g_baud, g_pull, (unsigned long)g_rxBytes);
  }

  while (Serial.available()) {
    char c = (char)Serial.read();
    if (c == '\n' || c == '\r') {
      line.trim();
      if (line.length()) {
        if      (line.equalsIgnoreCase("cap"))  capture(6000);
        else if (line == "d") pullTest("pull-down", INPUT_PULLDOWN);
        else if (line == "u") pullTest("pull-up",   INPUT_PULLUP);
        else if (line == "f") pullTest("floating",  INPUT);
        else if (line.equalsIgnoreCase("uart")) uartOn(g_baud);
        else if (line.equalsIgnoreCase("at"))   { for (int i=0;i<10;i++){ Serial.printf("  AT %d: ",i+1); if (sendAT("AT",800)) {Serial.println("\n  -> OK"); break;} Serial.println(); delay(300);} }
        else if (line.equalsIgnoreCase("scan")) baudScan();
        else if (line == "?") help();
        else if (line.length() > 1 && (line[0]=='b'||line[0]=='B') && isDigit(line[1])) {
          uint32_t r = line.substring(1).toInt();
          if (r >= 300) uartOn(r);
        }
        else sendAT(line, 3000);
        line = "";
      }
    } else line += c;
  }
}

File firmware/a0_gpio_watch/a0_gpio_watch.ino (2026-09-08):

// Edge watcher on GPIO16 = MiBUS1_RX = SIM7080G_TX (modem TX, via U1 B1).
//
// Prints every transition with a timestamp and how long the previous state
// lasted. The SHORTEST duration seen is one bit period, which gives the baud
// rate directly:  8.7 us = 115200,  17.4 us = 57600,  26 us = 38400,
//                52 us = 19200,    104 us = 9600.
//
// Nothing here touches PWRKEY. Pulse it by hand while this runs.
//
// Build with USB CDC On Boot = Enabled, otherwise Serial lands on UART0 and
// drives this very pin.

#define WATCH_PIN 16

struct Ev {
  uint32_t us;
  uint8_t  level;
};

static const uint16_t kBufSize = 512;
static volatile Ev       g_buf[kBufSize];
static volatile uint16_t g_head = 0;
static volatile uint16_t g_tail = 0;
static volatile uint32_t g_dropped = 0;

static uint32_t g_edges   = 0;
static uint32_t g_minPulse = 0xFFFFFFFF;
static uint32_t g_lastUs  = 0;
static uint8_t  g_lastLvl = 0;
static const char *g_mode = "floating";

static void IRAM_ATTR onEdge() {
  uint16_t next = (uint16_t)((g_head + 1) % kBufSize);
  if (next == g_tail) { g_dropped++; return; }
  g_buf[g_head].us    = micros();
  g_buf[g_head].level = (uint8_t)digitalRead(WATCH_PIN);
  g_head = next;
}

static void setMode(const char *name, uint8_t mode) {
  detachInterrupt(digitalPinToInterrupt(WATCH_PIN));
  pinMode(WATCH_PIN, mode);
  g_mode = name;
  delay(5);
  Serial.printf("\n-- input mode: %s, line now reads %s\n", name,
                digitalRead(WATCH_PIN) ? "HIGH" : "LOW");
  if (mode == INPUT_PULLDOWN)
    Serial.println("   stays HIGH = something is really driving it."
                   "  goes LOW = the line is floating.");
  if (mode == INPUT_PULLUP)
    Serial.println("   stays LOW = something is really pulling it down."
                   "  goes HIGH = floating.");
  attachInterrupt(digitalPinToInterrupt(WATCH_PIN), onEdge, CHANGE);
}

static void resetStats() {
  noInterrupts();
  g_head = g_tail = 0;
  g_dropped = 0;
  interrupts();
  g_edges = 0;
  g_minPulse = 0xFFFFFFFF;
  Serial.println("\n-- counters cleared");
}

static void banner() {
  Serial.println();
  Serial.println("========================================");
  Serial.printf(" GPIO%d edge watcher  (modem TX line)\n", WATCH_PIN);
  Serial.println("========================================");
  Serial.println("Pulse PWRKEY to GND by hand and watch this.");
  Serial.println();
  Serial.println("  f = float (plain input)   u = pull-up");
  Serial.println("  d = pull-down             r = reset counters");
  Serial.println();
  Serial.println("Shortest pulse = one bit time:");
  Serial.println("  8.7us=115200  17us=57600  26us=38400  52us=19200  104us=9600");
  Serial.println();
}

void setup() {
  Serial.begin(115200);
  pinMode(WATCH_PIN, INPUT);
  delay(1500);
  banner();
  g_lastLvl = digitalRead(WATCH_PIN);
  g_lastUs  = micros();
  Serial.printf("start: line is %s\n\n", g_lastLvl ? "HIGH" : "LOW");
  attachInterrupt(digitalPinToInterrupt(WATCH_PIN), onEdge, CHANGE);
}

void loop() {
  // Drain the ISR ring buffer.
  while (g_tail != g_head) {
    Ev e;
    noInterrupts();
    e = *(const Ev *)&g_buf[g_tail];
    g_tail = (uint16_t)((g_tail + 1) % kBufSize);
    interrupts();

    uint32_t held = e.us - g_lastUs;
    g_edges++;
    if (held < g_minPulse && held > 0) g_minPulse = held;

    // Only print the first 200 edges of a burst; a real UART frame would
    // otherwise flood the console faster than it can be read.
    if (g_edges <= 200) {
      Serial.printf("[%8lu us] %s -> %s   (held %lu us)\n",
                    (unsigned long)e.us,
                    g_lastLvl ? "HIGH" : "LOW ",
                    e.level   ? "HIGH" : "LOW ",
                    (unsigned long)held);
    } else if (g_edges == 201) {
      Serial.println("... further edges suppressed, see the 2 s summary ...");
    }

    g_lastUs  = e.us;
    g_lastLvl = e.level;
  }

  // Periodic summary so a quiet line is still reported.
  static uint32_t lastReport = 0;
  static uint32_t lastEdges  = 0;
  if (millis() - lastReport >= 2000) {
    lastReport = millis();
    uint32_t d = g_edges - lastEdges;
    lastEdges = g_edges;

    Serial.printf("[%s] level=%s  edges=%lu (+%lu)  ",
                  g_mode,
                  digitalRead(WATCH_PIN) ? "HIGH" : "LOW",
                  (unsigned long)g_edges, (unsigned long)d);
    if (g_minPulse != 0xFFFFFFFF) {
      Serial.printf("min pulse=%lu us", (unsigned long)g_minPulse);
      if (g_minPulse >= 7 && g_minPulse <= 11)        Serial.print("  -> ~115200");
      else if (g_minPulse >= 15 && g_minPulse <= 20)  Serial.print("  -> ~57600");
      else if (g_minPulse >= 23 && g_minPulse <= 30)  Serial.print("  -> ~38400");
      else if (g_minPulse >= 45 && g_minPulse <= 60)  Serial.print("  -> ~19200");
      else if (g_minPulse >= 95 && g_minPulse <= 115) Serial.print("  -> ~9600");
    } else {
      Serial.print("no edges yet");
    }
    if (g_dropped) Serial.printf("  [dropped %lu]", (unsigned long)g_dropped);
    Serial.println();
  }

  while (Serial.available()) {
    char c = (char)Serial.read();
    if (c == 'f') setMode("floating", INPUT);
    else if (c == 'u') setMode("pull-up", INPUT_PULLUP);
    else if (c == 'd') setMode("pull-down", INPUT_PULLDOWN);
    else if (c == 'r') resetStats();
  }
}

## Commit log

2026-09-08 remove A0 base board
    [Blue_Screw_Terminal_3DModel-STEP-1.STEP, CRJ011-ML1-TH--3DModel-STEP-1.STEP, FreeCADScrewterminal.step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]
2026-09-08 chore(wmbus): remove temp-freerouting.dsn
    [temp-freerouting.dsn]
2026-09-08 docs(readme): add base board and module docs, update features
